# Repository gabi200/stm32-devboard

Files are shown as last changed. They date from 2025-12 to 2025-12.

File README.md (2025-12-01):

# stm32-devboard
Simple, cost-effective **STM32** development board with onboard voltage regulator and I2C EEPROM. The provided files include both the electrical schematic and the PCB layout. The design has been fabricated at JLCPCB and validated in real-life operation. 

**Caution: Please note that the component assembly was performed manually, so the design does not take into consideration automated assembly.**
## Board specifications

 - STM32L4-family microcontroller
 - AMS1117 voltage regulator
 - M24256E-F 256-Kbit I2C EEPROM
 - GPIO and Debug/Programming headers
 - 3.3V I/O voltage
 - Maximum recommended VIN voltage: 12V

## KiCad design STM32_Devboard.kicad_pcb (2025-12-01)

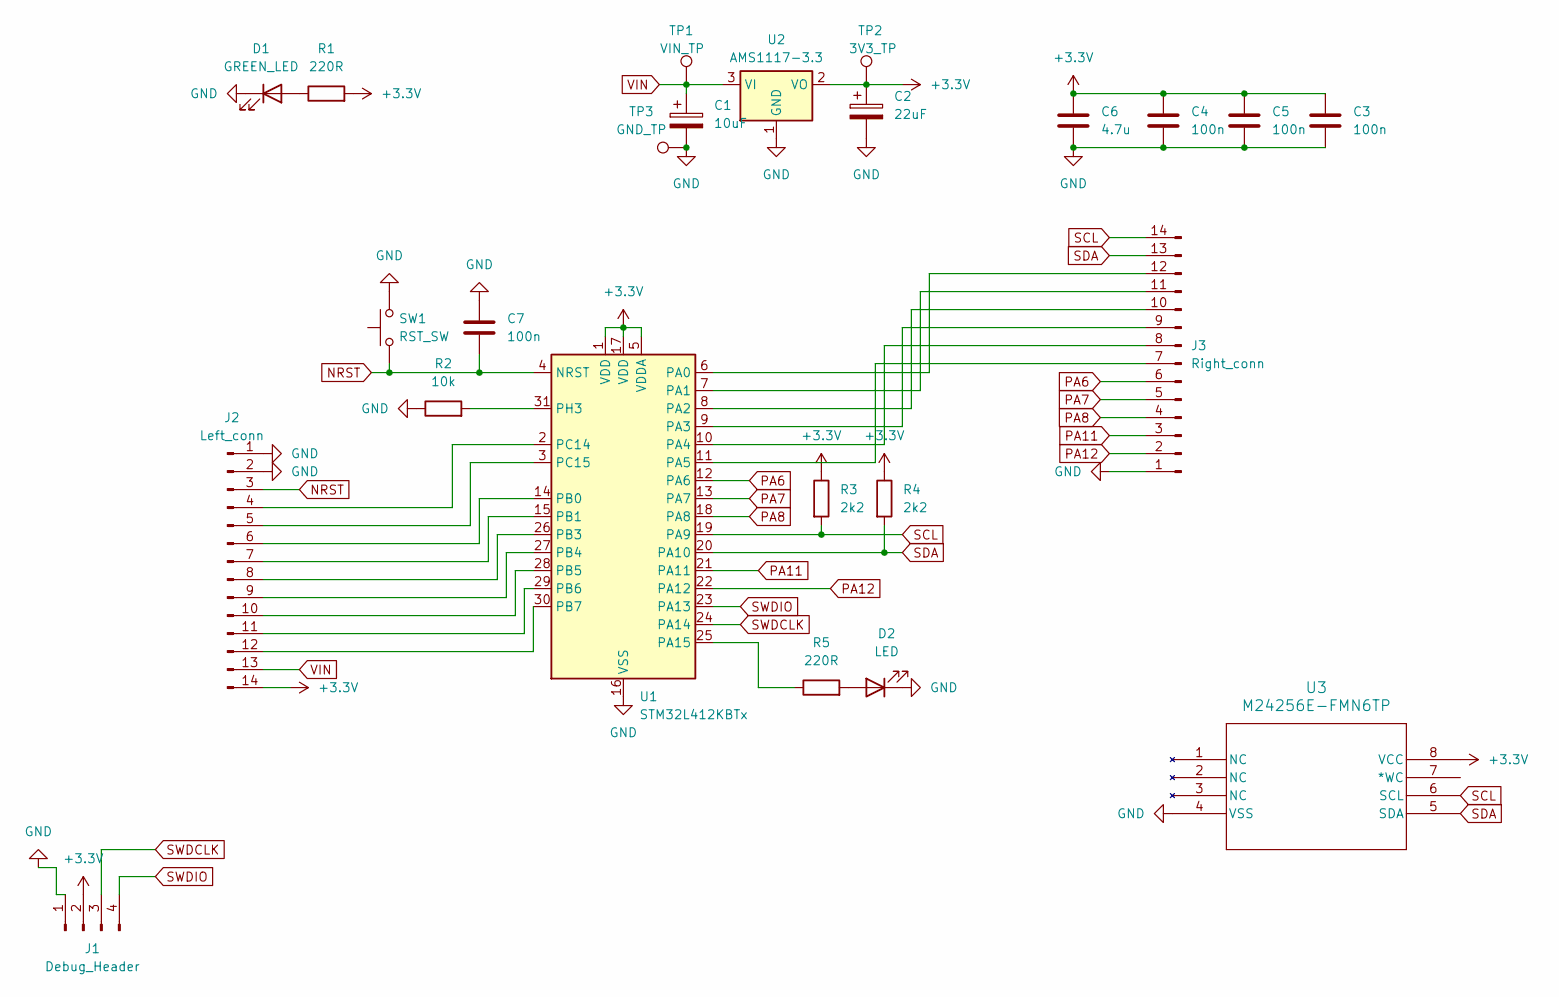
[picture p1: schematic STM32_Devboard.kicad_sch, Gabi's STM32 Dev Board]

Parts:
C1: 10uF; CP_EIA-3528-21_Kemet-B_Pad1.50x2.35mm_HandSolder
C2: 22uF; CP_EIA-6032-28_Kemet-C_Pad2.25x2.35mm_HandSolder
C3, C4, C5, C7: 100n; C_1206_3216Metric_Pad1.33x1.80mm_HandSolder
C6: 4.7u; C_1206_3216Metric_Pad1.33x1.80mm_HandSolder
D1: GREEN_LED; LED_Yuji_5730
D2: LED; LED_Yuji_5730
J1: Debug_Header; PinHeader_1x04_P2.54mm_Vertical
J2: Left_conn; PinHeader_1x14_P2.54mm_Vertical
J3: Right_conn; PinHeader_1x14_P2.54mm_Vertical
R1, R5: 220R; R_1206_3216Metric_Pad1.30x1.75mm_HandSolder
R2: 10k; R_1206_3216Metric_Pad1.30x1.75mm_HandSolder
R3, R4: 2k2; R_1206_3216Metric_Pad1.30x1.75mm_HandSolder
SW1: RST_SW; SW_PUSH_6mm_H9.5mm
TP1: VIN_TP; TestPoint_Pad_D1.5mm
TP2: 3V3_TP; TestPoint_Pad_D1.5mm
TP3: GND_TP; TestPoint_Pad_D1.5mm
U1: STM32L412KBTx; LQFP-32_7x7mm_P0.8mm
U2: AMS1117-3.3; SOT-223-3_TabPin2
U3: M24256E-FMN6TP; SO8N_4X5X1P27_STM

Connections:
+3.3V: C2.1, C3.1, C4.1, C5.1, C6.1, J1.2, J2.14, R1.2, R3.1, R4.1, TP2.1, U1.1 (VDD), U1.5 (VDDA), U1.17 (VDD), U2.2 (VO), U3.8 (VCC)
GND: C1.2, C2.2, C3.2, C4.2, C5.2, C6.2, C7.1, D1.1 (K), D2.1 (K), J1.1, J2.1, J2.2, J3.1, R2.1, SW1.2, TP3.1, U1.16 (VSS), U1.32 (VSS), U2.1 (GND), U3.4 (VSS)
NRST: C7.2, J2.3, SW1.1, U1.4 (NRST)
unnamed: D1.2 (A), R1.1
unnamed: D2.2 (A), R5.2
unnamed: J2.4, U1.2 (PC14)
unnamed: J2.5, U1.3 (PC15)
unnamed: J2.6, U1.14 (PB0)
unnamed: J2.7, U1.15 (PB1)
unnamed: J2.8, U1.26 (PB3)
unnamed: J2.9, U1.27 (PB4)
unnamed: J2.10, U1.28 (PB5)
unnamed: J2.11, U1.29 (PB6)
unnamed: J2.12, U1.30 (PB7)
unnamed: J3.7, U1.11 (PA5)
unnamed: J3.8, U1.10 (PA4)
unnamed: J3.9, U1.9 (PA3)
unnamed: J3.10, U1.8 (PA2)
unnamed: J3.11, U1.7 (PA1)
unnamed: J3.12, U1.6 (PA0)
unnamed: R5.1, U1.25 (PA15)
unnamed: R2.2, U1.31 (PH3)
PA6: J3.6, U1.12 (PA6)
PA7: J3.5, U1.13 (PA7)
PA8: J3.4, U1.18 (PA8)
PA11: J3.3, U1.21 (PA11)
PA12: J3.2, U1.22 (PA12)
SCL: J3.14, R3.2, U1.19 (PA9), U3.6 (SCL)
SDA: J3.13, R4.2, U1.20 (PA10), U3.5 (SDA)
SWDCLK: J1.3, U1.24 (PA14)
SWDIO: J1.4, U1.23 (PA13)
VIN: C1.1, J2.13, TP1.1, U2.3 (VI)

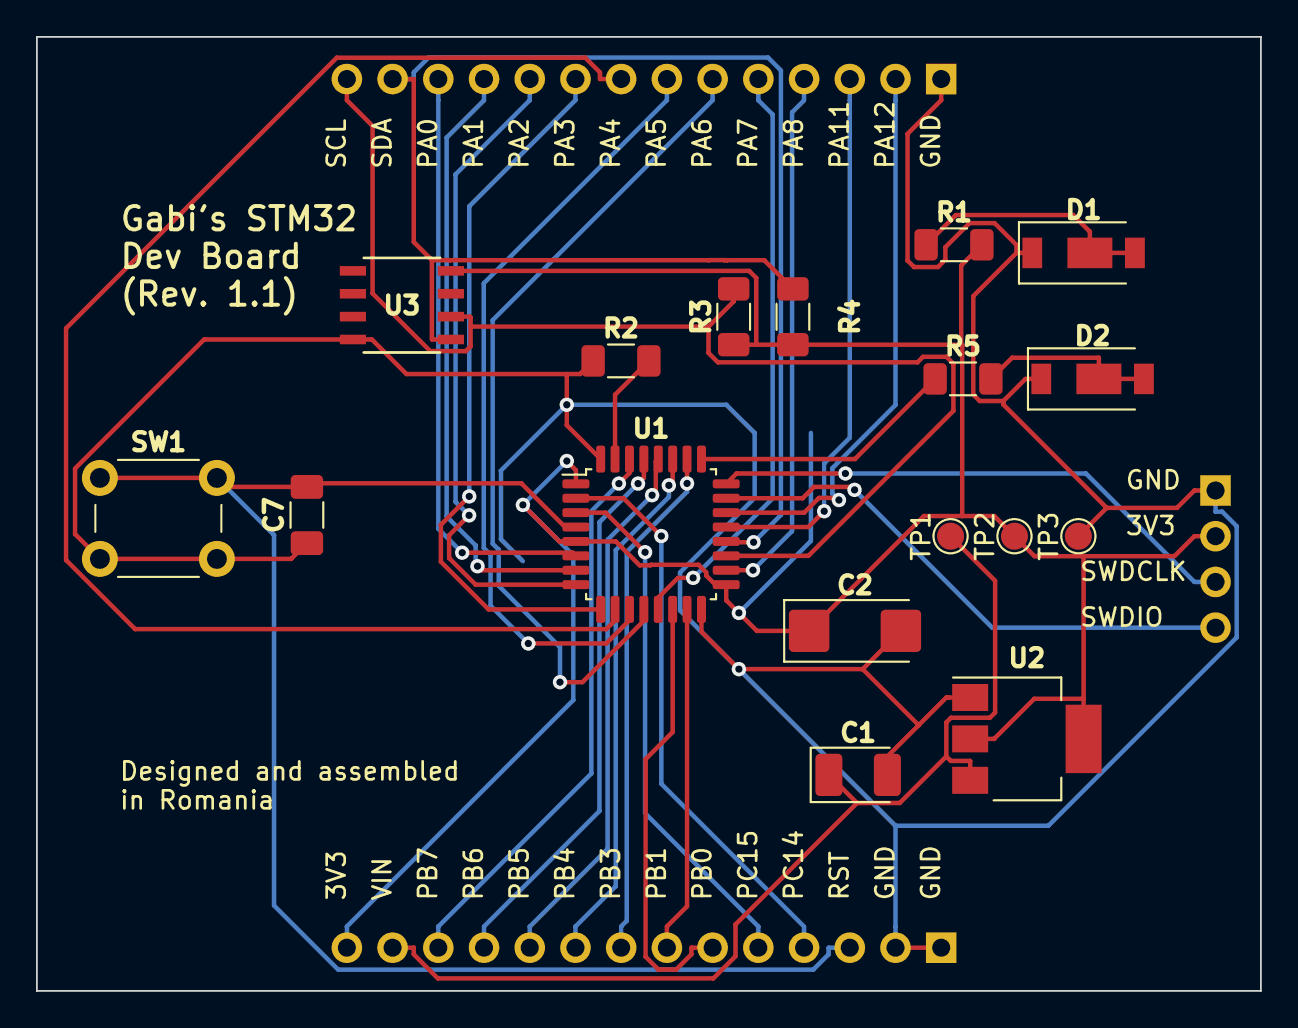
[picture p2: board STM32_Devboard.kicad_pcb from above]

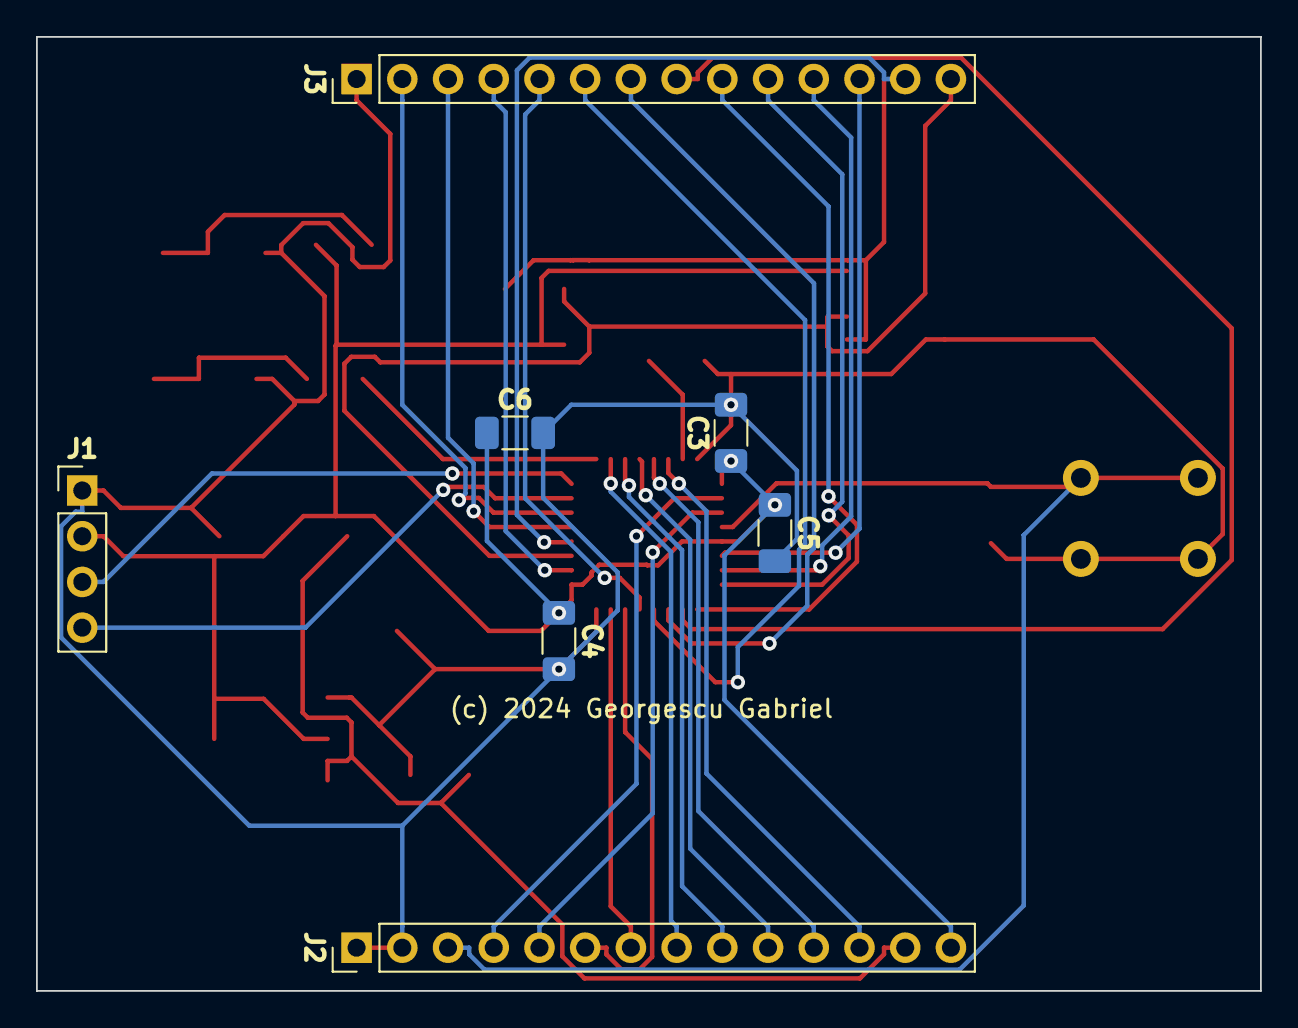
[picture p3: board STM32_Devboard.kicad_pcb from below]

Board: 2 copper layers, 68.0 x 53.0 mm, 24 parts (7 on the bottom side), 32 nets.

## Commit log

2025-12-01 Added board files
    [STM32_Devboard.kicad_pcb, STM32_Devboard.kicad_sch]
2025-12-01 updated README
    Added a caution note regarding manual assembly of components.

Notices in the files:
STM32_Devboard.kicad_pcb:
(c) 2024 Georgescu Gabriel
